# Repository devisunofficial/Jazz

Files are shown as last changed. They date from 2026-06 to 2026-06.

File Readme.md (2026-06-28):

# Jazz

Jazz is a bluetooth speaker that uses ESP32 for bluetooth connection

It focuses on minimalism and uses Audiophile grade equipments for good soundquality

### Features:

 - Compact design 
 - Capacitive Sensor to enter pairing mode
 - Toggle switch to On-Off speaker.
 - Daytone Speaker and Passive Radiator

### CAD Model:
It has 3 separate printed pieces. The Enclousure, the Speaker Holder to support driver and passive radiator, and Top mesh to cover driver.
Made in Autodesk Fusion.

### PCB:
Here's my PCB! It was made in KiCad. 

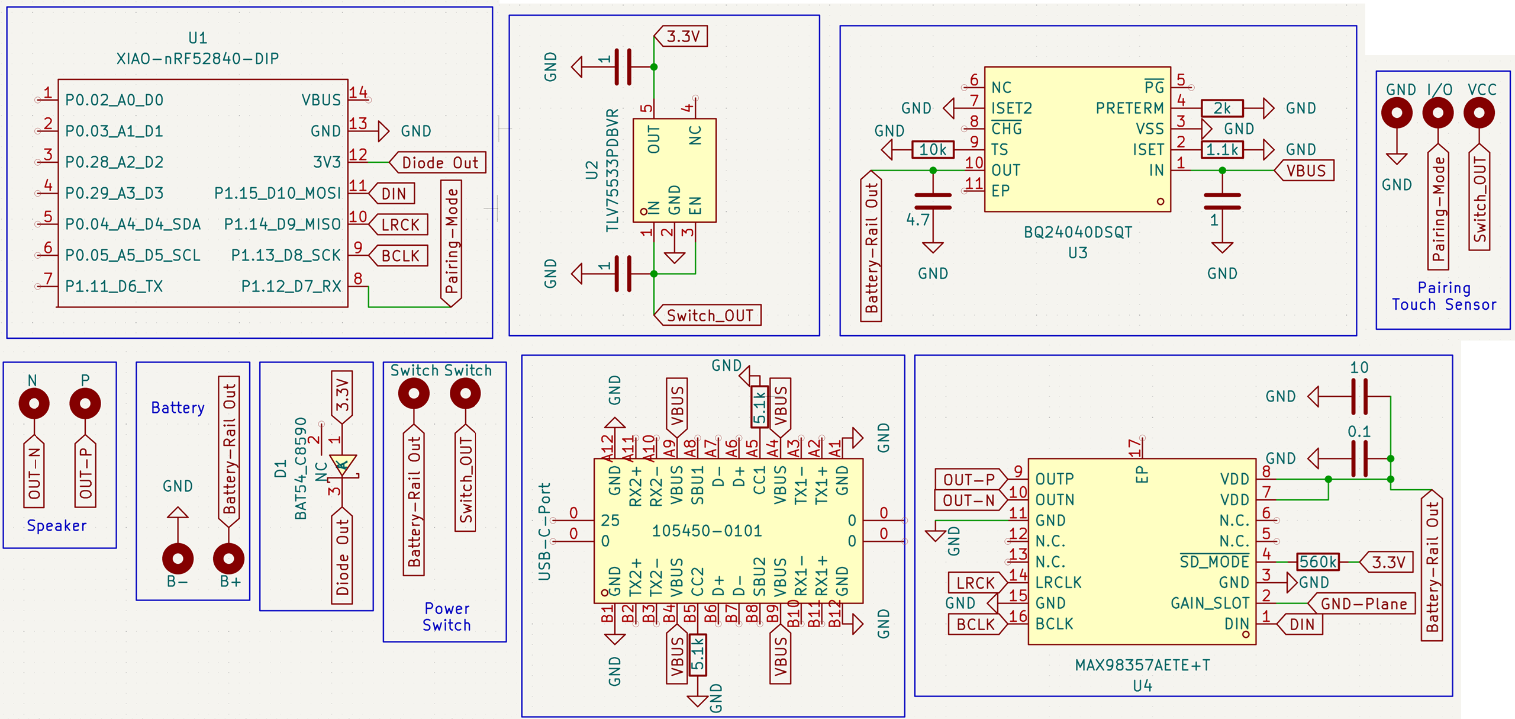
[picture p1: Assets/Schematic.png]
Schematic : 
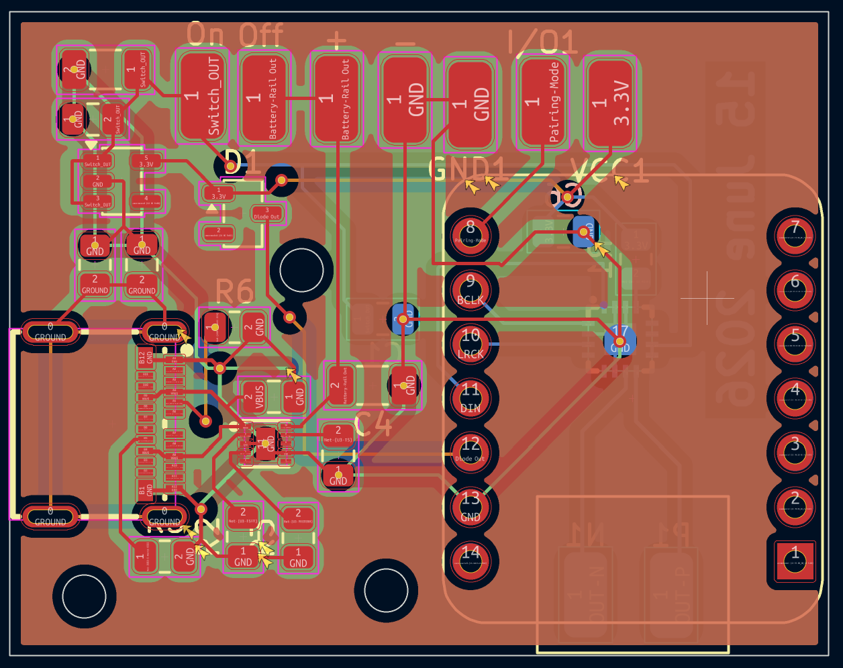
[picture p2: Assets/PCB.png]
PCB Footprint : 

### Firmware Overview:
Currently Firmware is underdevelopment so there is some time to finished product.
This speaker uses C++ firmware and Arduino IDE for Flashing.

### Assembly Instructions :
1. Flash Firmware in XIAO ESO32
2. Solder Pairing Switch, Kill Switch, Speaker, Battery
3. Test everything works
4. Apply Epoxy layer(not neccessary though but better if we do) inside shell to prevent air from leaking
5. Glue togetther the Speaker and Passive Radiater to Speaker holder (to prevent air from leaking) along with screws
6. Screw Speaker holder and Top Mesh to Encloudure.

### BOM Table
|Name|Use|Quantity|Distributer|
|-----|---|---|---|
|Battery|Power Source|1|Robu|
|PCB|Main-Circuit|1|JLCPCB|
|Toggle switch|On-Off|1|Amazon|
|XIAO ESP32|Bluetooth SoC|1|Amazon|
|Speaker|Main Driver|1|Parts Express|
|Capacitive Touch Button|Pairing Mode|1|Amazon|
|AirTight Glue|Prevent Air Leaking|1|Amazon|

### Extra Stuff
I have provided an extra 3D printing Part in PR folder in CAD Folder because rather then paying $88 in shipping.
I didn't made that, and I don't have refinement in skills to make that. 
#### **CREDITS**  https://www.thingiverse.com/zx82net

Also I have added all screenshots of Cart in Screenshots_Cart Folder

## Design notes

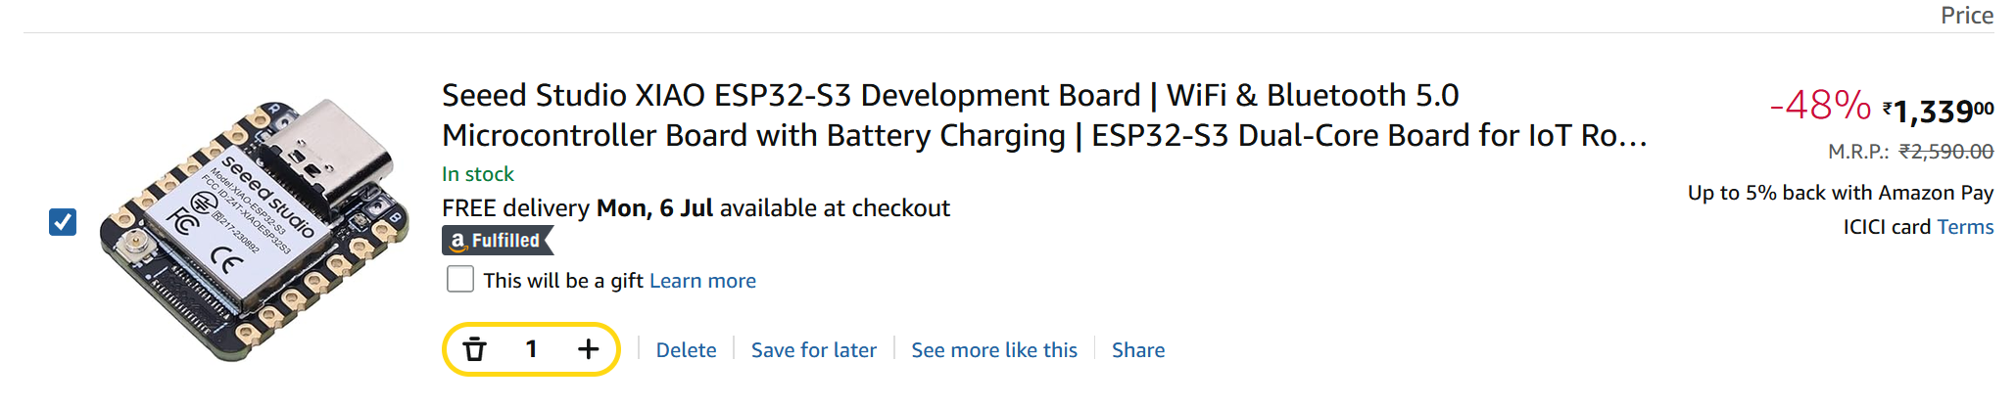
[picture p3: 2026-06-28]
ScreenShots_Cart/Screenshot 2026-06-28 174259.png

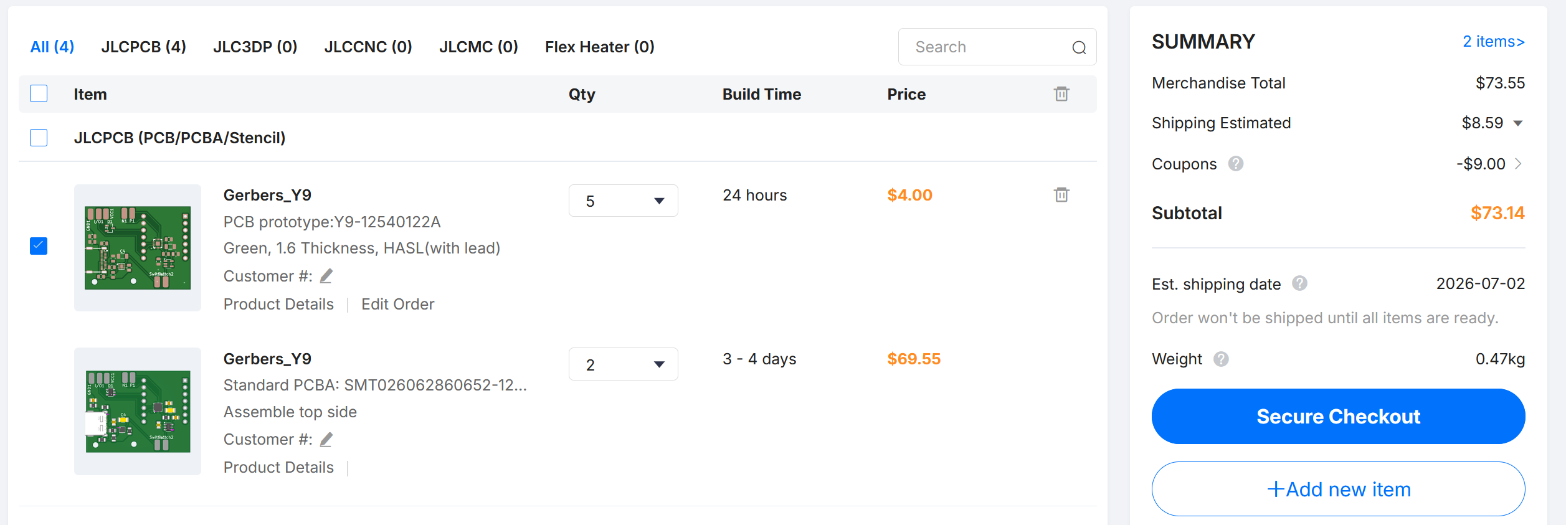
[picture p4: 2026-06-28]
ScreenShots_Cart/Screenshot 2026-06-28 163557.png

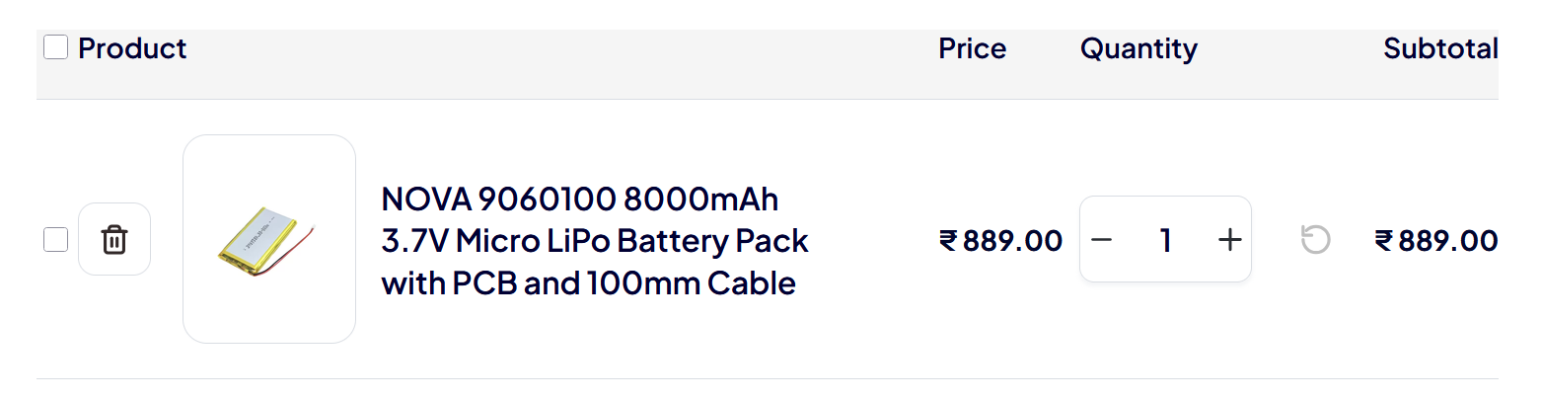
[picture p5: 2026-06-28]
ScreenShots_Cart/Screenshot 2026-06-28 171851.png

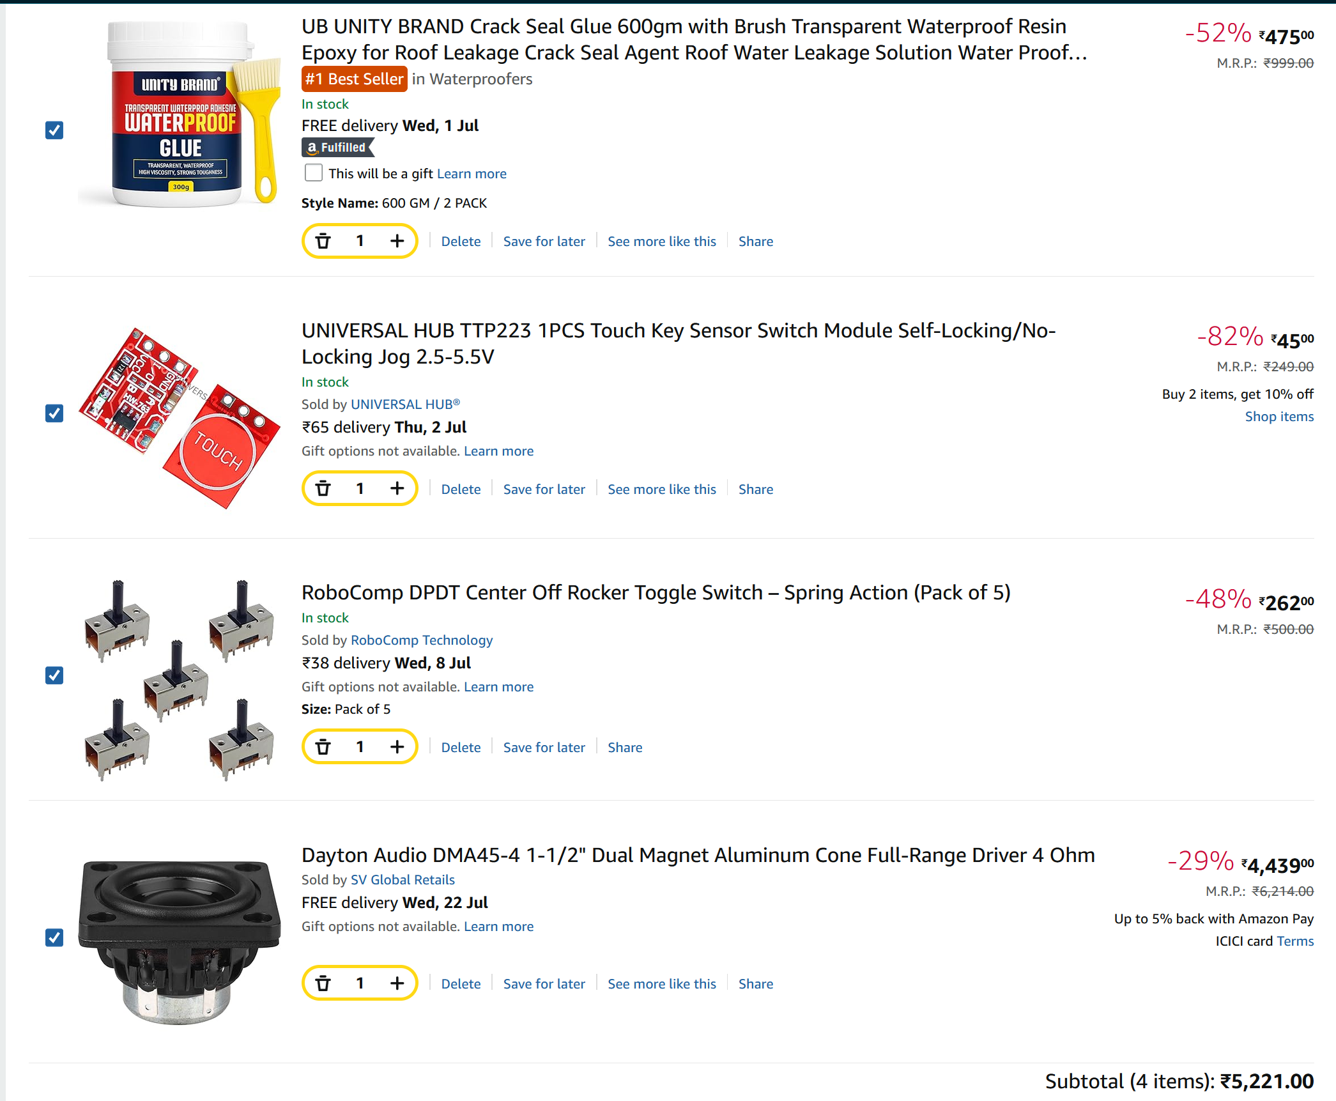
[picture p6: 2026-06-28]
ScreenShots_Cart/Screenshot 2026-06-28 173051.png

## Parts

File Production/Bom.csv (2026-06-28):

Comment | Designator | Footprint
0.1 | C1 | C_0805_2012Metric
10 | C2 | C_1206_3216Metric
1 | C3, C5, C6 | C_0805_2012Metric
4.7 | C4 | C_1206_3216Metric
4.7n | C7 | C_0805_2012Metric
BAT54_C8590 | D1 | SOT-23-3
560k | R1 | R_0805_2012Metric
1.1k | R2 | R_0805_2012Metric
2k | R3 | R_0805_2012Metric
10k | R4 | R_0805_2012Metric
5.1k | R5, R6 | R_0805_2012Metric
1M | R7 | R_0805_2012Metric
TLV75533PDBVR | U2 | SOT-23-5
BQ24040DSQT | U3 | WSON-10_L2.0-W2.0-P0.40-TL-EP
MAX98357AETE+T | U4 | TQFN-16_L3.0-W3.0-P0.50-BL-EP1.5
105450-0101 | USB-C-Port1 | USB-C-SMD_TYPE-C-USB-18

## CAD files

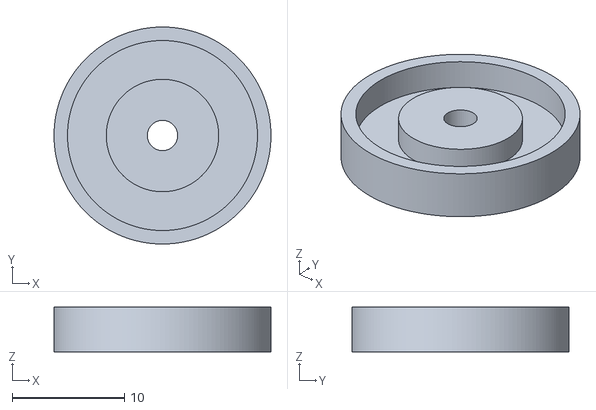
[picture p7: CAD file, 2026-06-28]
CAD/PR/ND65-PR_compatible_Passive_radiator_small_single_piece_v3_Hard_bits_1_inner_Hard_bits.stl
19.3 x 19.3 x 4.00

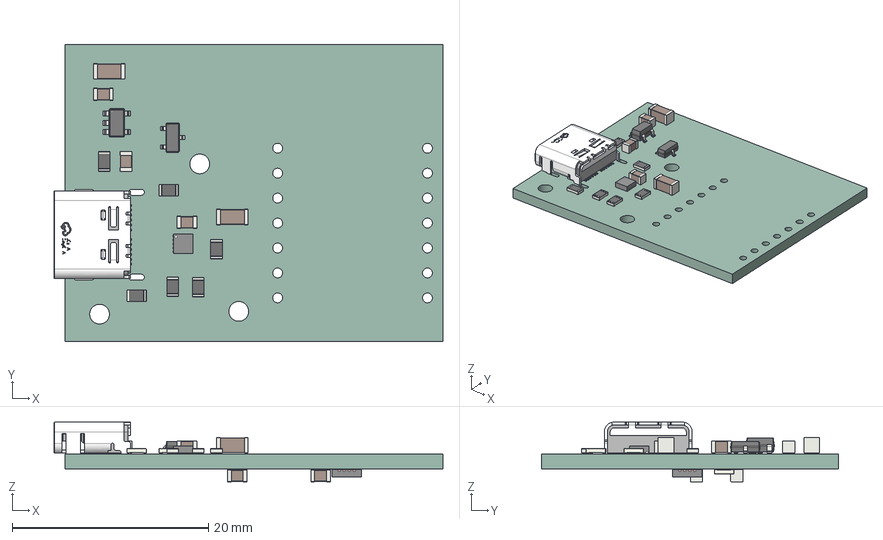
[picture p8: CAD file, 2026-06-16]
PCB & Schematic/Jazz.step
39.6 x 30.2 x 6.09 mm
R_0805_2012Metric x 7
C_1206_3216Metric x 2
C_0805_2012Metric x 5
WSON-10_L2.0-W2.0-P0.40-TL-EP
SOT-23-5
USB-C-SMD_TYPE-C-USB-18
SOT-23-3
TQFN-16_L3.0-W3.0-P0.50-BL-EP1.5
Jazz_PCB

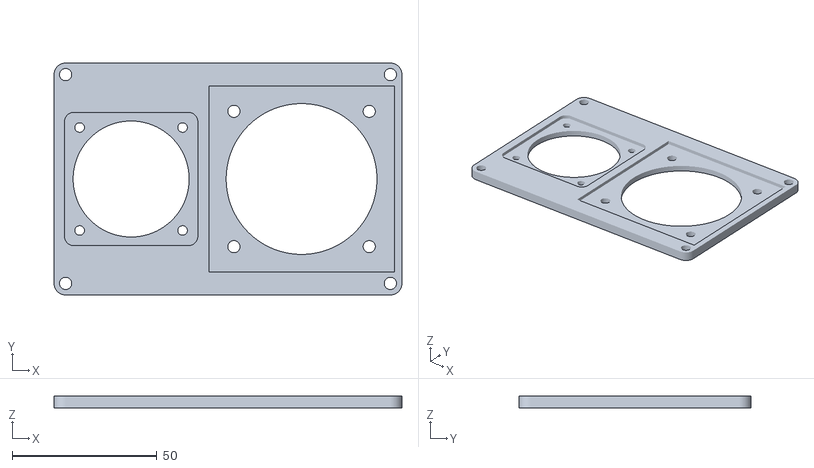
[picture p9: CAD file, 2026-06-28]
Production/StlFiles/Speaker_Holder.stl
120.0 x 80.0 x 4.00

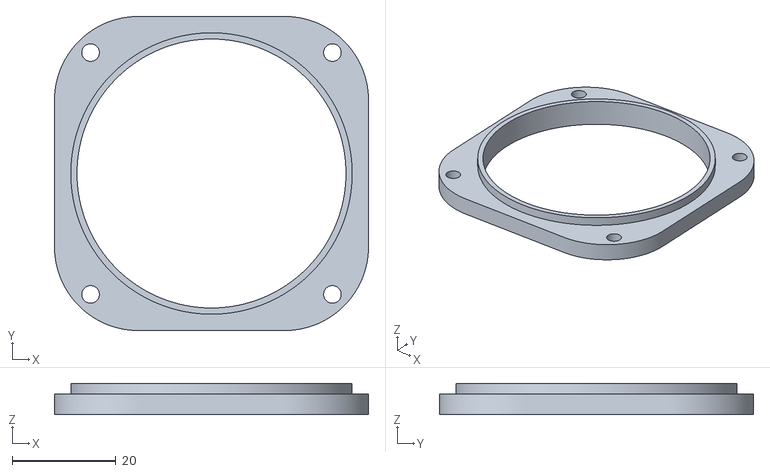
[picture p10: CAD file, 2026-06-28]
CAD/PR/ND65-PR_compatible_Passive_radiator_small_single_piece_v3_Hard_bits_1_outer_Hard_bits.stl
60.6 x 60.6 x 6.00

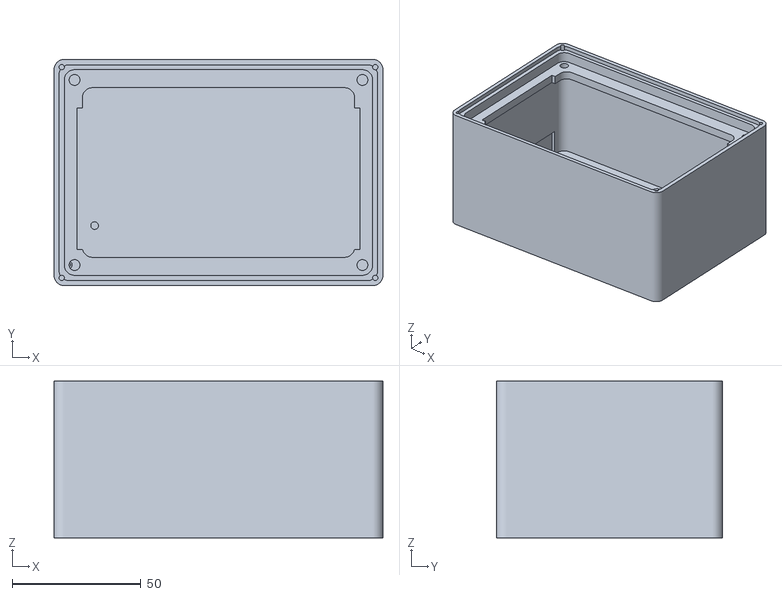
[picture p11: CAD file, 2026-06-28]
Production/StlFiles/Enclosure.stl
128.0 x 88.0 x 61.0

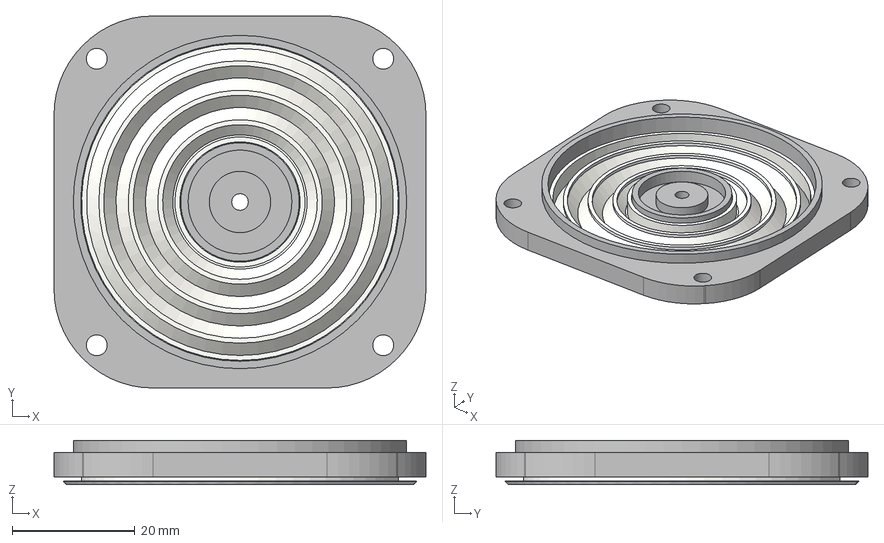
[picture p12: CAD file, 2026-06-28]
CAD/PR/Passive_radiator_small_single_piece_v3.step
60.6 x 60.6 x 7.20 mm
surround
Hard bits

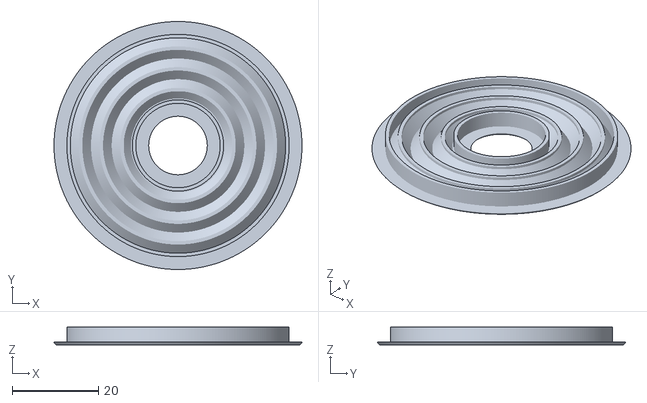
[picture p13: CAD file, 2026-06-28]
CAD/PR/ND65-PR_compatible_Passive_radiator_small_single_piece_v3_surround_1_Surround_surround.stl
57.6 x 57.6 x 4.10

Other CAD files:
CAD/StepFiles/Speaker_Holder.step
CAD/StepFiles/TopMesh.step
CAD/StepFiles/Enclosure.step
CAD/PR/Passive_radiator_ND65-PR_compatible.f3d

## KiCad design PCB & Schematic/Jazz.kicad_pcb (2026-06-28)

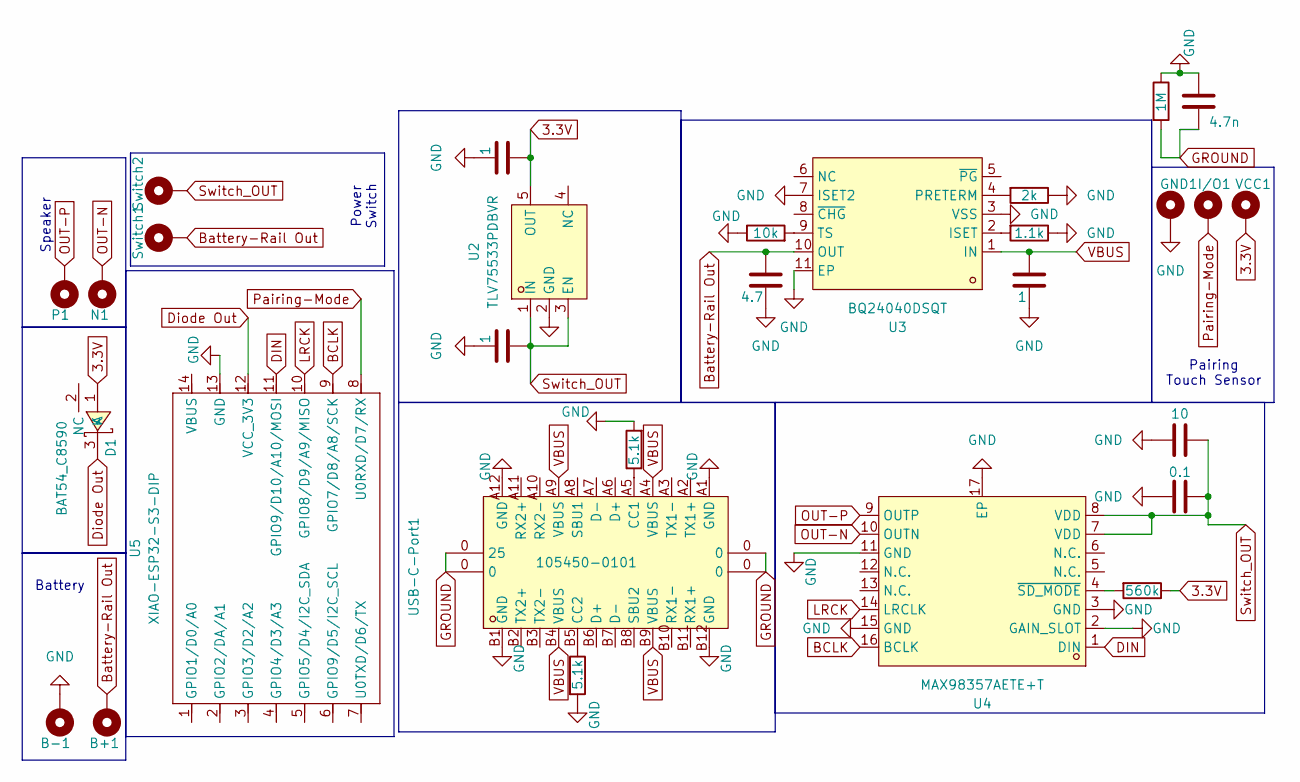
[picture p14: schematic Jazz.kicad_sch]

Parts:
B+1: MountingHole_Pad; SolderWirePad_1x01_SMD_2x4mm
B-1: MountingHole_Pad; SolderWirePad_1x01_SMD_2x4mm
C1: 0.1; C_0805_2012Metric
C2: 10; C_1206_3216Metric
C3, C5, C6: 1; C_0805_2012Metric
C4: 4.7; C_1206_3216Metric
C7: 4.7n; C_0805_2012Metric
D1: BAT54_C8590; SOT-23-3; MPN BAT54; LCSC Part C8590
GND1: MountingHole_Pad; SolderWirePad_1x01_SMD_2x4mm
I/O1: MountingHole_Pad; SolderWirePad_1x01_SMD_2x4mm
N1: MountingHole_Pad; SolderWirePad_1x01_SMD_2x4mm
P1: MountingHole_Pad; SolderWirePad_1x01_SMD_2x4mm
R1: 560k; R_0805_2012Metric
R2: 1.1k; R_0805_2012Metric
R3: 2k; R_0805_2012Metric
R4: 10k; R_0805_2012Metric
R5, R6: 5.1k; R_0805_2012Metric
R7: 1M; R_0805_2012Metric
Switch1, Switch2: MountingHole_Pad; SolderWirePad_1x01_SMD_2x4mm
U2: TLV75533PDBVR; SOT-23-5; MPN TLV75533PDBVR; LCSC Part C404027
U3: BQ24040DSQT; WSON-10_L2.0-W2.0-P0.40-TL-EP; MPN BQ24040DSQT; LCSC Part C2876332
U4: MAX98357AETE+T; TQFN-16_L3.0-W3.0-P0.50-BL-EP1.5; MPN MAX98357AETE+T; LCSC Part C910544
U5: XIAO-ESP32-S3-DIP; XIAO-Generic-Thruhole-14P-2.54-21X17.8MM
USB-C-Port1: 105450-0101; USB-C-SMD_TYPE-C-USB-18; MPN 1054500101; LCSC Part C134092
VCC1: MountingHole_Pad; SolderWirePad_1x01_SMD_2x4mm

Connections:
3.3V: C6.2, D1.1 (A), R1.1, U2.5 (OUT), VCC1.1 (1_1)
BCLK: U4.16 (BCLK), U5.9 (GPIO7/D8/A8/SCK)
Battery-Rail Out: B+1.1 (1_1), C4.2, Switch1.1 (1_1), U3.10 (OUT)
DIN: U4.1 (DIN), U5.11 (GPIO9/D10/A10/MOSI)
Diode Out: D1.3 (K), U5.12 (VCC_3V3)
GND: B-1.1 (1_1), C1.2, C2.2, C3.1, C4.1, C5.1, C6.1, C7.1, GND1.1 (1_1), R2.1, R3.1, R4.1, R5.2, R6.2, R7.1, U2.2 (GND), U3.3 (VSS), U3.7 (ISET2), U3.11 (EP), U4.2 (GAIN_SLOT), U4.3 (GND), U4.11 (GND), U4.15 (GND), U4.17 (EP), U5.13 (GND), USB-C-Port1.A1 (GND), USB-C-Port1.A12 (GND), USB-C-Port1.B1 (GND), USB-C-Port1.B12 (GND)
GROUND: C7.2, R7.2, USB-C-Port1.0
LRCK: U4.14 (LRCLK), U5.10 (GPIO8/D9/A9/MISO)
unnamed: R2.2, U3.2 (ISET)
unnamed: R3.2, U3.4 (PRETERM)
unnamed: R4.2, U3.9 (TS)
unnamed: R1.2, U4.4 (~SD_MODE)
unnamed: R6.1, USB-C-Port1.A5 (CC1)
unnamed: R5.1, USB-C-Port1.B5 (CC2)
OUT-N: N1.1 (1_1), U4.10 (OUTN)
OUT-P: P1.1 (1_1), U4.9 (OUTP)
Pairing-Mode: I/O1.1 (1_1), U5.8 (U0RXD/D7/RX)
Switch_OUT: C1.1, C2.1, C5.2, Switch2.1 (1_1), U2.1 (IN), U2.3 (EN), U4.7 (VDD), U4.8 (VDD)
VBUS: C3.2, U3.1 (IN), USB-C-Port1.A4 (VBUS), USB-C-Port1.A9 (VBUS), USB-C-Port1.B4 (VBUS), USB-C-Port1.B9 (VBUS)

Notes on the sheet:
Battery
Pairing Touch Sensor
Power Switch
Speaker

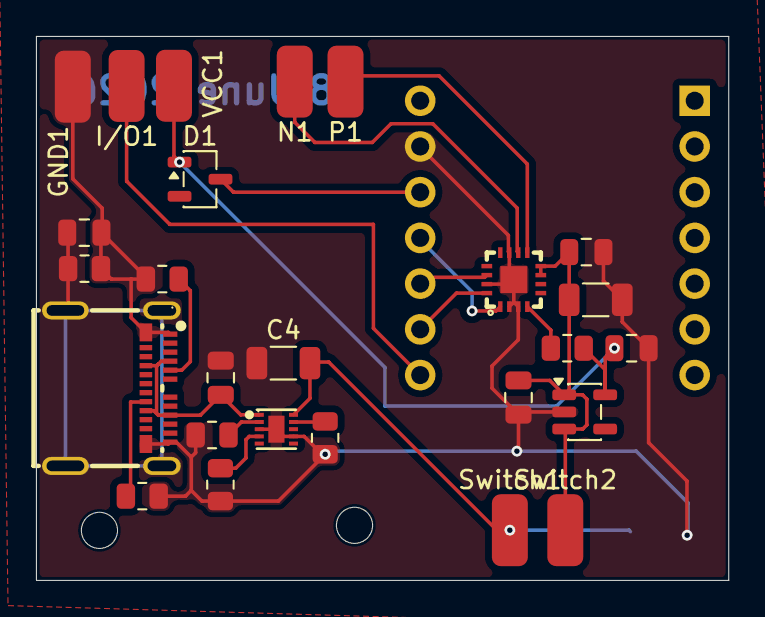
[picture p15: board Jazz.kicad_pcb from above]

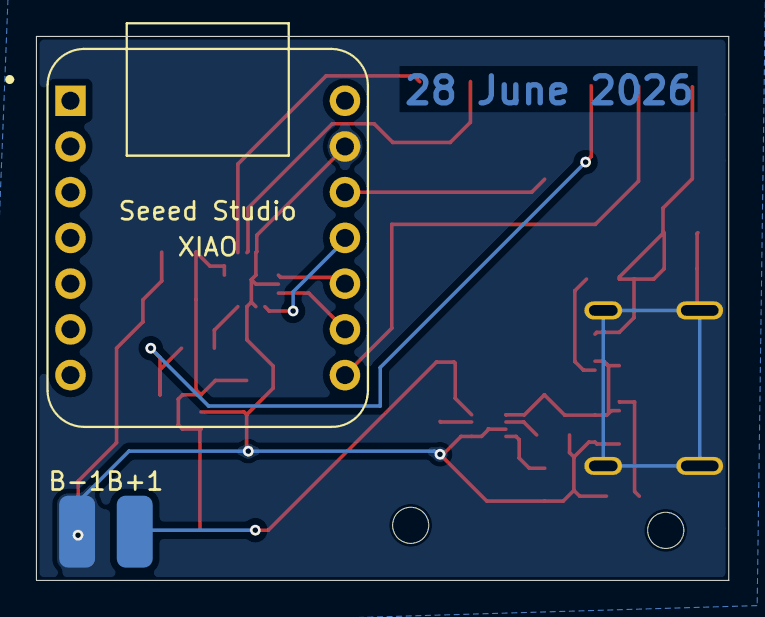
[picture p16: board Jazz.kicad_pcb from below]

Board: 2 copper layers, 38.5 x 30.2 mm, 29 parts (3 on the bottom side), 19 nets.

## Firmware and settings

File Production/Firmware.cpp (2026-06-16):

#include "BluetoothA2DPSink.h"

#define I2S_BCLK      26   
#define I2S_LRCK      25   
#define I2S_DIN       22   
#define PAIRING_PIN   13   

const char* bluetooth_name = "Jazz";


unsigned long touch_start_time = 0;       
bool touch_was_active = false;            
const unsigned long required_hold_time = 10000; 


BluetoothA2DPSink a2dp_sink;

void setup() {
  Serial.begin(115200);
  Serial.println("[SYSTEM] Booting Speaker Engine...");

  
  pinMode(PAIRING_PIN, INPUT_PULLDOWN);

  
  i2s_pin_config_t my_pin_config = {
    .bcl_io_num = I2S_BCLK,
    .ws_io_num = I2S_LRCK,
    .data_out_num = I2S_DIN,
    .data_in_num = I2S_PIN_NOT_USED
  };
  a2dp_sink.set_pin_config(my_pin_config);

  
  a2dp_sink.set_mono_downmix(true); 

  
  a2dp_sink.set_auto_reconnect(true); 
  
  a2dp_sink.start(bluetooth_name);
  Serial.println("[BLUETOOTH] Engine active. Searching for saved devices...");
}

void loop() {
    

  bool current_touch_state = digitalRead(PAIRING_PIN);

  
  if (current_touch_state == HIGH) {
    
    if (!touch_was_active) {
        
      touch_start_time = millis();
      touch_was_active = true;
      Serial.println("[TOUCH] Pad touched. Keep holding for 10s to FORGET phone memory.");
    } 
    else {
      unsigned long elapsed_time = millis() - touch_start_time;
      
      
      if (elapsed_time % 1000 < 50) { 
        Serial.print("[TOUCH] Timing: ");
        Serial.print(elapsed_time / 1000);
        Serial.println("/10 seconds elapsed.");
      }

      
      if (elapsed_time >= required_hold_time) {
        Serial.println("[SYSTEM] 10 seconds reached! Executing Full Cache Memory Wipe...");
        
        
        if (a2dp_sink.is_connected()) {
          Serial.println("[BLUETOOTH] Disconnecting existing host link...");
          a2dp_sink.disconnect();
        }
        
        
        Serial.println("[FLASH] Wiping saved device MAC keys from memory...");
        a2dp_sink.clean_last_connection(); 
        
        Serial.println("[BLUETOOTH] Speaker is now completely blank. Ready for new phone registration!");
        
        
        touch_was_active = false; 
        delay(1500); 
      }
    }
  } 
  
  else {
    
    if (touch_was_active) {
      Serial.println("[TOUCH] Finger lifted early. Stored pairing memory intact.");
      touch_was_active = false;
      touch_start_time = 0;
    }
  }

  delay(50);
}

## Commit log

2026-06-16 Readme Done
    Updated the Readme.md to include additional details about the BOM table and corrected formatting issues.
2026-06-16 Bom & Readme
    [Bom.csv]
2026-06-28 Update Readme with assembly instructions and formatting
    Added assembly instructions and fixed formatting issues.
2026-06-28 Possibly Done
    [Bom.csv, Enclosure.step, Enclosure.stl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]
